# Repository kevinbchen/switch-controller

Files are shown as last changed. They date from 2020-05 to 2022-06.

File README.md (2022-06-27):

# switch-controller

This is a simple electronics project to wirelessly control a Nintendo Switch using an Xbox One controller.
There are 2 main parts:
- The **transmitter** unit acts as a usb host for the Xbox controller; it reads in the controller input and periodically sends the input data to the receiver via bluetooth.
- The **receiver** unit connects to the Nintendo Switch (via the dock) and emulates a 3rd-party controller with the given input data.



Note that there are commercial 3rd-party controllers and wireless adapters that achieve the same thing much more conveniently; this was mainly a fun side project to get back into electronics and 3d-printing. Of course, having control over the software does enable things like a turbo mode for specific buttons (to hit rocks and chop trees more easily in Animal Crossing!).

Although the software is currently written for an Xbox One Controller, other usb controllers should also work, assuming the usb host shield library support them. In addition, the transmitter can also be replaced by a PC, opening up potential for some basic automation.

## Repository Contents

- **SwitchControllerReceiver/** - Arduino sketch for the receiver
- **SwitchControllerTransmitter/** - Arduino sketch for the transmitter
- **BluetoothAT/** - Helper Arduino sketch for sending AT commands to the bluetooth modules
- **enclosures/** - Fusion 360 and .stl files for the  3d-printed enclosures

## Hardware
**Transmitter** components:
- Arduino Pro Mini (3.3V)
- USB host shield (Mini)
- HC-05 bluetooth module
- MT3608 boost converter

The transmitter is powered directly from the Xbox controller's 2 AA batteries, stepped up to 5V. This gets regulated back down to 3.3V for all the components, but USB VBUS still needs 5V. Probably pretty inefficient, but needs no modification to the controller itself , besides exposing connections to the batteries. In total, the transmitter draws ~120 mA from the batteries (~100 mA from the controller itself).

**Receiver** components:
- Arduino Pro Micro (5V)
- HC-06 bluetooth module

The receiver is powered by via USB (5V). The HC-06 has its own regulator for VCC, so we just need a voltage divider for the module's RX pin.

## Software
Dependencies:
- [Arduino SwitchJoystick Library](https://github.com/HackerLoop/Arduino-JoyCon-Library-for-Nintendo-Switch) (for receiver - note installation instructions for setting the USB vid/pid) 
- [USB Host Library Rev.2.0](https://github.com/felis/USB_Host_Shield_2.0) (for transmitter)

The **transmitter** uses the USB Host Library to read in the Xbox controller state. It encodes the state into 7 bytes and sends them over the bluetooth serial link, along with an initial `0xFF` byte as a sentinel. A state "packet" is sent every 10ms, or immediately if the controller state changes (ignoring small changes in analog values). The 7 data bytes sent are:
```
    byte buttons1;  // 0:Y, 1:B, 2:A, 3:X, 4:L, 5:R, 6:ZL, 7:ZR
    byte buttons2;  // 0:-, 1:+, 2:Lstick, 3:Rstick, 4:Home, 5:Capture
    byte lx;
    byte ly;
    byte rx;
    byte ry;
    byte dir;
```
The button bytes are simple bitmasks. The `lx/ly/rx/ry` bytes are in [0, 254] and represent each axis of the left/right analog sticks, wiht 128 being center (255 avoided because of sentinel). The `dir` byte is in [0, 8] and represents the number of 45 degree clockwise increments from up for the directional pad, with 8 being no direction.

The **receiver** simply reads in these packets, and uses the SwitchJoystick Library to send these inputs to the Nintendo Switch. There's some simple logic for skipping packets if the serial RX queue is being flooded.

## Misc Notes

### Latency
Latency was intially a concern, but I was able to reduce it somewhat with a combination of:
- Sending a packet immediately on controller state changes
- Using the hardware serial for the bluetooth on the transmitter (though unfortunately means can't use serial debugging)
- Increasing bluetooth baudrate to 38400

I don't have qualitative numbers, but I think it's fairly reasonable now.

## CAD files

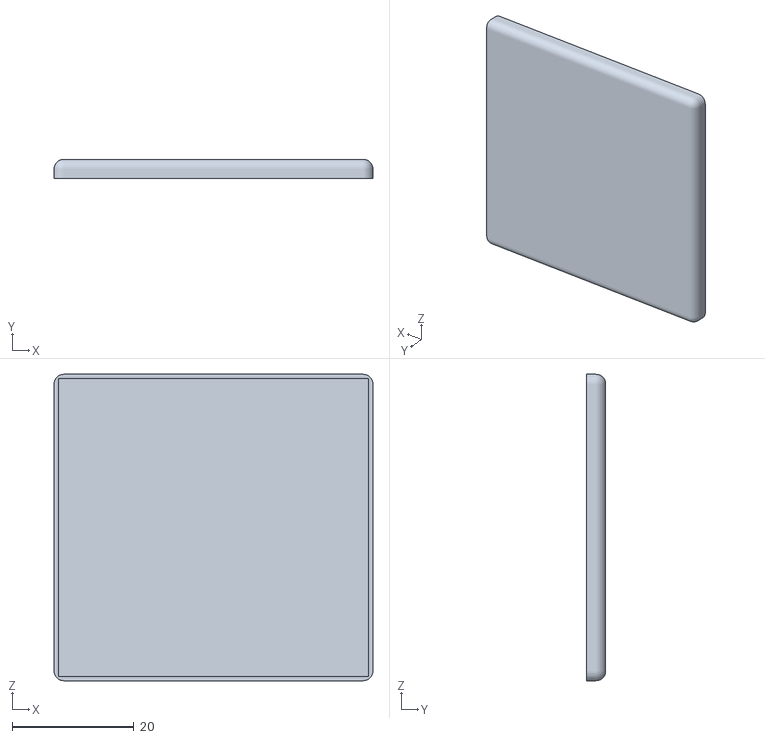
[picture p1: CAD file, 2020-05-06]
enclosures/transmitter_top.stl
52.5 x 3.20 x 50.4

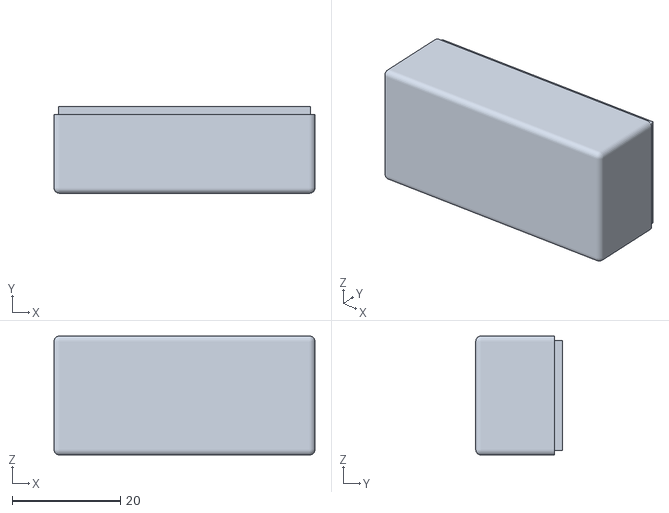
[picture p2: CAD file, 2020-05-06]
enclosures/receiver_bottom.stl
48.2 x 16.0 x 22.0

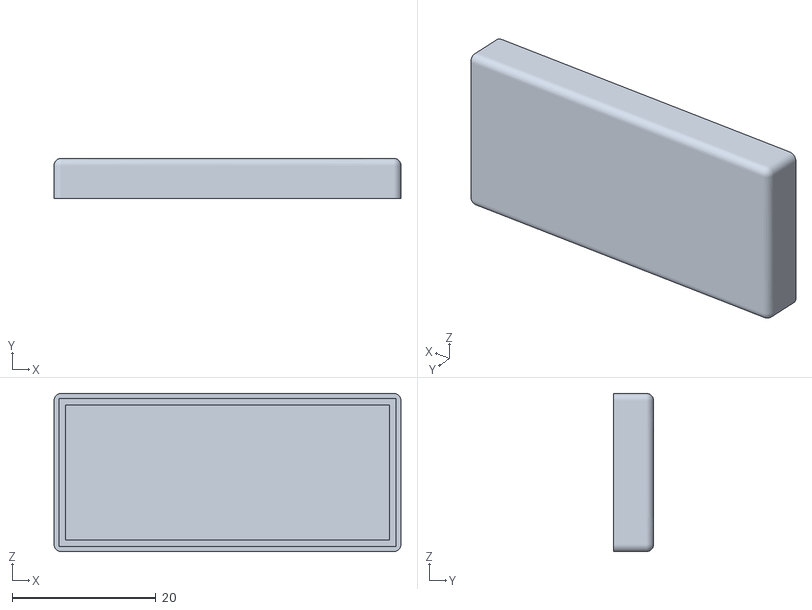
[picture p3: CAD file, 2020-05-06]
enclosures/receiver_top.stl
48.2 x 5.60 x 22.0

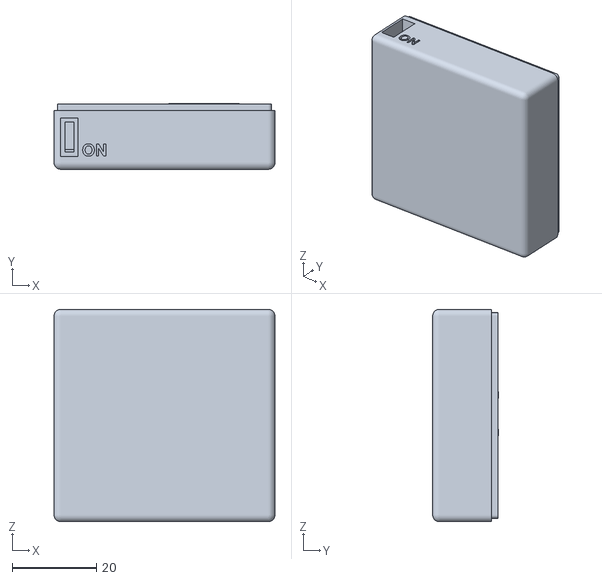
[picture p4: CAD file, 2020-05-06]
enclosures/transmitter_bottom.stl
52.5 x 15.6 x 50.4

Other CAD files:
enclosures/ReceiverCase.f3d
enclosures/TransmitterCase.f3d

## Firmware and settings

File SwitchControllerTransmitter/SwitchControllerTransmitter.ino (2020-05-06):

/*
   Sketch for the transmitter unit that the Xbox One controller plugs into.
   Hardware: Arduino Pro Mini (3.3V), USB Host Shield Mini, HT-05 module.
*/
#include <XBOXONE.h>

// Set to 1 to print packets
#define DEBUG 0

#define SEND_MS 10
#define TOGGLE_MS 20

#define NUM_STATE_BYTES 7
union State {
  struct {
    byte buttons1;  // 0:Y, 1:B, 2:A, 3:X, 4:L, 5:R, 6:ZL, 7:ZR
    byte buttons2;  // 0:-, 1:+, 2:Lstick, 3:Rstick, 4:Home, 5:Capture
    byte lx;
    byte ly;
    byte rx;
    byte ry;
    byte dir;
  } data;
  byte raw[NUM_STATE_BYTES];
};

#define BTSerial Serial

USB Usb;
XBOXONE Xbox(&Usb);
State lastState;
bool turboMode = false;
bool turboModeClick = false;
bool turboToggle = false;
unsigned long lastToggleTime = 0;
unsigned long lastSendTime = 0;

byte convertAnalogValueX(int16_t value) {
  byte byteVal = (byte)min(((value >> 8) + 128), 254);
  if (abs(byteVal - 128) < 16) {
    byteVal = 128;
  }
  return byteVal;
}

byte convertAnalogValueY(int16_t value) {
  // Flip y-axis
  if (value == -32768) {
    value = -32767;
  }
  value = -value;
  byte byteVal = (byte)min(((value >> 8) + 128), 254);
  if (abs(byteVal - 128) < 16) {
    byteVal = 128;
  }
  return byteVal;
}

// Return true if states are different enough to warrant immediate sending
bool diffStates(State& state1, State& state2) {
  return (state1.data.buttons1 != state2.data.buttons1 ||
          state1.data.buttons2 != state2.data.buttons2 ||
          state1.data.dir != state2.data.dir ||
          abs(state1.data.lx - state2.data.lx) >= 16 ||
          abs(state1.data.ly - state2.data.ly) >= 16 ||
          abs(state1.data.rx - state2.data.rx) >= 16 ||
          abs(state1.data.ry - state2.data.ry) >= 16);
}

byte setButtonValue(byte& buttons, int i, bool value) {
  int mask = (1 << i);
  buttons = (buttons & ~mask) | ((value << i) & mask);
  return buttons;
}

void setup() {
  //Serial.begin(9600);
  BTSerial.begin(38400);

  if (Usb.Init() == -1) {
    //Serial.print(F("\r\nOSC did not start"));
    while (1);
  }
  //Serial.print(F("\r\nXBOX USB Library Started"));

  lastState.data.buttons1 = 0x00;
  lastState.data.buttons2 = 0x00;
  lastState.data.lx = 128;
  lastState.data.ly = 128;
  lastState.data.rx = 128;
  lastState.data.ry = 128;
  lastState.data.dir = 8;

  lastToggleTime = millis();
  lastSendTime = millis();
}

void loop() {
  unsigned long currTime = millis();
  Usb.Task();
  if (!Xbox.XboxOneConnected) {
    delay(1);
    return;
  }

  // Read in xbox controller state
  State state;
  state.data.buttons1 = 0x00;
  state.data.buttons2 = 0x00;
  state.data.lx = 128;
  state.data.ly = 128;
  state.data.rx = 128;
  state.data.ry = 128;
  state.data.dir = 8;

  // byte buttons1;  // 0:Y, 1:B, 2:A, 3:X, 4:L, 5:R, 6:ZL, 7:ZR
  // byte buttons2;  // 0:-, 1:+, 2:Lstick, 3:Rstick, 4:Home, 5:Capture
  const ButtonEnum buttons1Mapping[6] = {X, A, B, Y, L1, R1};
  for (int i = 0; i < 6; i++) {
    state.data.buttons1 |= Xbox.getButtonPress(buttons1Mapping[i]) ? (1 << i) : 0;
  }
  if (Xbox.getButtonPress(L2) > 512) {
    state.data.buttons1 |= (1 << 6);
  }
  if (Xbox.getButtonPress(R2) > 512) {
    state.data.buttons1 |= (1 << 7);
  }
  const ButtonEnum buttons2Mapping[6] = {BACK, START, L3, R3, XBOX, SYNC};
  for (int i = 0; i < 6; i++) {
    state.data.buttons2 |= Xbox.getButtonPress(buttons2Mapping[i]) ? (1 << i) : 0;
  }

  state.data.lx = convertAnalogValueX(Xbox.getAnalogHat(LeftHatX));
  state.data.ly = convertAnalogValueY(Xbox.getAnalogHat(LeftHatY));
  state.data.rx = convertAnalogValueX(Xbox.getAnalogHat(RightHatX));
  state.data.ry = convertAnalogValueY(Xbox.getAnalogHat(RightHatY));

  int dirX = 0;
  int dirY = 0;
  if (Xbox.getButtonPress(UP)) {
    dirY += 1;
  }
  if (Xbox.getButtonPress(DOWN)) {
    dirY -= 1;
  }
  if (Xbox.getButtonPress(LEFT)) {
    dirX -= 1;
  }
  if (Xbox.getButtonPress(RIGHT)) {
    dirX += 1;
  }
  int dirIdx = (dirY + 1) * 3 + (dirX + 1);
  const byte dirMapping[9] = {5, 4, 3, 6, 8, 2, 7, 0, 1};
  state.data.dir = dirMapping[dirIdx];

  // If both + and - are clicked, toggle turbo mode
  if ((state.data.buttons2 & B00000011) == B00000011) {
    turboModeClick = true;
  } else if ((state.data.buttons2 & B00000011) == B00000000) {
    Xbox.setRumbleOff();
    if (turboModeClick) {
      //Serial.println("turbo enabled");
      turboMode = !turboMode;
      turboToggle = 1;
      turboModeClick = false;
    }
  }
  if (turboMode) {
    // Only toggle A (2) and Y (0) for now
    if (state.data.buttons1 & (1 << 2)) {
      setButtonValue(state.data.buttons1, 2, turboToggle);
    }
    if (state.data.buttons1 & (1 << 0)) {
      setButtonValue(state.data.buttons1, 0, turboToggle);
    }
    if (currTime - lastToggleTime >= TOGGLE_MS) {
      lastToggleTime = currTime;
      turboToggle = !turboToggle;
    }
  }

  // Send an update every SEND_MS, or sooner if the state changed enough
  if (currTime - lastSendTime >= SEND_MS || diffStates(lastState, state)) {
    lastState = state;
    lastSendTime = currTime;
    BTSerial.write(0xFF);
    BTSerial.write(state.raw, NUM_STATE_BYTES);
    
    //for (int i = 0; i < NUM_STATE_BYTES; i++) {
    //  Serial.print(" " + String(state.raw[i]));
    //}
    //Serial.println("");
  }

  // Read response
  if (BTSerial.available()) {
    byte data = BTSerial.read();
    //Serial.println("got response: " + String(data));
  }
}

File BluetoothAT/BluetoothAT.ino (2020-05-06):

/*
   Simple sketch for sending AT commands to a HC-05/HC-06 module.
*/
#include <SoftwareSerial.h>

#if 1
// Transmitter
SoftwareSerial PCSerial(2, 3);
#define BTSerial Serial
#define BT_BAUD 38400
#else
// Receiver
#define PCSerial Serial
#define BTSerial Serial1
#define BT_BAUD 38400
#endif

void setup() {
  PCSerial.begin(9600);
  PCSerial.println("Enter AT commands:");

  // HC-06 default serial speed is 9600
  BTSerial.begin(BT_BAUD);
}

void loop() {
  if (BTSerial.available()) {
    PCSerial.write(BTSerial.read());
  }
  if (PCSerial.available()) {
    BTSerial.write(PCSerial.read());
  }
}

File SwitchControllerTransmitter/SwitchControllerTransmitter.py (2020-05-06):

import pygame
import serial
import time


bluetooth_serial = serial.Serial('COM10', 9600, timeout=0)
#print("connected!")
#input("wait")




# Define some colors.
BLACK = pygame.Color('black')
WHITE = pygame.Color('white')


# This is a simple class that will help us print to the screen.
# It has nothing to do with the joysticks, just outputting the
# information.
class TextPrint(object):
    def __init__(self):
        self.reset()
        self.font = pygame.font.Font(None, 20)

    def tprint(self, screen, textString):
        textBitmap = self.font.render(textString, True, BLACK)
        screen.blit(textBitmap, (self.x, self.y))
        self.y += self.line_height

    def reset(self):
        self.x = 10
        self.y = 10
        self.line_height = 15

    def indent(self):
        self.x += 10

    def unindent(self):
        self.x -= 10

def axis_float_to_byte(value):
    int_val = min(max(0, int(value * 128 + 128)), 254)
    if abs(int_val - 128) < 16:
        int_val = 128
    return int_val


pygame.init()
screen = pygame.display.set_mode((500, 700))

pygame.joystick.init()

xbox_joystick = None
for i in range(pygame.joystick.get_count()):
    joystick = pygame.joystick.Joystick(i)
    joystick.init()
    print(joystick.get_name())
    if "xbox" in joystick.get_name().lower():
        xbox_joystick = joystick
joystick = xbox_joystick

clock = pygame.time.Clock()
done = False


textPrint = TextPrint()

last_poll_time = None
poll_delays = []

# -------- Main Program Loop -----------
while not done:
    #
    # EVENT PROCESSING STEP
    #
    # Possible joystick actions: JOYAXISMOTION, JOYBALLMOTION, JOYBUTTONDOWN,
    # JOYBUTTONUP, JOYHATMOTION
    for event in pygame.event.get(): # User did something.
        if event.type == pygame.QUIT: # If user clicked close.
            done = True # Flag that we are done so we exit this loop.
        elif event.type == pygame.JOYBUTTONDOWN:
            print("Joystick button pressed.")
        elif event.type == pygame.JOYBUTTONUP:
            print("Joystick button released.")

    #
    # DRAWING STEP
    #
    # First, clear the screen to white. Don't put other drawing commands
    # above this, or they will be erased with this command.
    screen.fill(WHITE)
    textPrint.reset()

    # Get count of joysticks.
    joystick_count = pygame.joystick.get_count()

    textPrint.tprint(screen, "Number of joysticks: {}".format(joystick_count))
    textPrint.indent()


    # Get the name from the OS for the controller/joystick.
    name = joystick.get_name()
    textPrint.tprint(screen, "Joystick name: {}".format(name))

    # Usually axis run in pairs, up/down for one, and left/right for
    # the other.
    axes = joystick.get_numaxes()
    textPrint.tprint(screen, "Number of axes: {}".format(axes))
    textPrint.indent()

    for i in range(axes):
        axis = joystick.get_axis(i)
        textPrint.tprint(screen, "Axis {} value: {:>6.3f}".format(i, axis))
    textPrint.unindent()

    buttons = joystick.get_numbuttons()
    textPrint.tprint(screen, "Number of buttons: {}".format(buttons))
    textPrint.indent()

    for i in range(buttons):
        button = joystick.get_button(i)
        textPrint.tprint(screen,
                         "Button {:>2} value: {}".format(i, button))
    textPrint.unindent()

    hats = joystick.get_numhats()
    textPrint.tprint(screen, "Number of hats: {}".format(hats))
    textPrint.indent()

    # Hat position. All or nothing for direction, not a float like
    # get_axis(). Position is a tuple of int values (x, y).
    for i in range(hats):
        hat = joystick.get_hat(i)
        textPrint.tprint(screen, "Hat {} value: {}".format(i, str(hat)))
    textPrint.unindent()


    # byte buttons1;  // 0:Y, 1:B, 2:A, 3:Z, 4:L, 5:R, 6:ZL, 7:ZR
    # byte buttons2;  // 0:-, 1:+, 2:Lstick, 3:Rstick, 4:Home, 5:Capture

    buttons1_mapping = [2, 0, 1, 3, 4, 5]
    buttons1 = 0
    for i, j in enumerate(buttons1_mapping):
        if j == -1:
            continue        
        buttons1 |= joystick.get_button(j) << i
    lr = joystick.get_axis(2)
    if lr >= 0.5:
        buttons1 |= 1 << 6
    elif lr <= -0.5:
        buttons1 |= 1 << 7

    buttons2_mapping = [6, 7, 8, 9, -1, -1]
    buttons2 = 0
    for i, j in enumerate(buttons2_mapping):
        if j == -1:
            continue
        buttons2 |= joystick.get_button(j) << i
    if joystick.get_button(7):
        if lr <= -0.5:
            buttons2 |= 1 << 4
        else:
            buttons2 |= 1 << 1
    if joystick.get_button(6):
        if lr >= 0.5:
            buttons2 |= 1 << 5
        else:
            buttons2 |= 1 << 0

    lx = axis_float_to_byte(joystick.get_axis(0))
    ly = axis_float_to_byte(joystick.get_axis(1))
    rx = axis_float_to_byte(joystick.get_axis(4))
    ry = axis_float_to_byte(joystick.get_axis(3))

    hat_x, hat_y = joystick.get_hat(0)
    hat_idx = (hat_y + 1) * 3 + (hat_x + 1)
    hat_mapping = [5, 4, 3, 6, 8, 2, 7, 0, 1]
    dir_pad = hat_mapping[hat_idx]
    
    textPrint.tprint(screen, f"{buttons1} {buttons2} {lx} {ly} {rx} {ry} {dir_pad}")


    #
    # ALL CODE TO DRAW SHOULD GO ABOVE THIS COMMENT
    #

    # Go ahead and update the screen with what we've drawn.
    pygame.display.flip()


    # Serial stuff
    data = bluetooth_serial.read()
    if len(data) == 1:
        curr_poll_time = pygame.time.get_ticks()
        delay = 0
        avg_poll_delay = 0
        if last_poll_time is not None:
            delay = (curr_poll_time - last_poll_time)
            poll_delays.insert(0, delay)
        if len(poll_delays) > 10:
            poll_delays = poll_delays[:10]
            avg_poll_delay = sum(poll_delays) / len(poll_delays)

        last_poll_time = curr_poll_time
        print(f"Got sync from receiver: avg delay {avg_poll_delay} {delay} {data}")

    bluetooth_serial.write(bytes([0xFF, buttons1, buttons2, lx, ly, rx, ry, dir_pad]))
    #bluetooth_serial.flush()


    # Limit to 20 frames per second.
    clock.tick(75)


# Close the window and quit.
# If you forget this line, the program will 'hang'
# on exit if running from IDLE.
pygame.quit()

bluetooth_serial.close()
